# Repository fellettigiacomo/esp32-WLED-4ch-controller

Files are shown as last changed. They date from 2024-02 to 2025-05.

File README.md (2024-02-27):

# esp32-WLED-4ch-controller
Hardware design for a 4 channel WLED controller with built in relays for power saving and level shifter for better signal integrity with long data cables.<br>
<br>

## Manufacturing
I tried to make this board as cheap as possibile using JLCPCB basics part for PCBA, however, since there are many extended parts the final cost should be around 25$/board + shipping
<br>All parts should be compatible with the JLCPCB assembly, otherwise, feel free to send me a pull request.
<br>Looking for a cheaper alternative? i've uploaded a version of the board without the esp32 related hardware, with the headers to plug a whole dev-kit, saving out on extended parts.

## Compatibility and capabilites
This PCB supports up to 4 addressable led strips:
Only strips that works with 5V are compatible. 
Compatible strips: WS2811 - WS2812B - TM1829 (and other with 5V, DATA, GND). Check [the wled wiki](https://kno.wled.ge/basics/compatible-led-strips/) for more info
<br>The board allows for a maximum current of around 100W (20A) max. Maximum current for a single relay is 10A (50W)

## Flashing
To flash the firmware, follow these steps:
- connect via USB-C or with serial UART (use test points TX, RX, 3.3V, GND)
- use the WLED web installer powered by Esp Web Tools at https://install.wled.me/
- connect to serial port and flash
- after installing, connect to the address provided from the web installer, or connect to the WLED AP
- done! enjoy your addressable IoT leds :D

## Licence
CERN Open Hardware License - S (CERN-OHL-S)

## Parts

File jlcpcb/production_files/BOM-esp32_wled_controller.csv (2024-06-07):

Comment | Designator | Footprint | LCSC
EL817 | U4,U5,U6,U7 | OPTO-SMD-4_L4.6-W6.5-P2.54-LS10.3-TL | C106900
1K | R3,R6,R7 | R_0402_1005Metric_Pad0.72x0.64mm_HandSolder | C11702
100nF | C1,C11,C12,C2,C4,C5 | C_0402_1005Metric_Pad0.74x0.62mm_HandSolder | C1525
1K | R13,R14,R15,R16,R17,R18,R19,R8 | R_0805_2012Metric_Pad1.20x1.40mm_HandSolder | C17513
4u7 | C6 | C_0805_2012Metric_Pad1.18x1.45mm_HandSolder | C1779
100R | R20,R21,R22,R23 | R_0402_1005Metric_Pad0.72x0.64mm_HandSolder | C25076
22R | R10,R11 | R_0402_1005Metric_Pad0.72x0.64mm_HandSolder | C25092
10K | R1,R2,R9 | R_0402_1005Metric_Pad0.72x0.64mm_HandSolder | C25744
5K1 | R4,R5 | R_0402_1005Metric_Pad0.72x0.64mm_HandSolder | C25905
USB_C_Receptacle_USB2.0_16P | J1 | USB_C_Receptacle_G-Switch_GT-USB-7010ASV | C2988369
SW_SPST | SW1,SW2 | SW_Push_1P1T_XKB_TS-1187A | C318884
SRD-05VDC-SL-C | K1,K2,K3,K4 | RELAY_SRD-05VDC-SL-C | C35449
SN74AHCT125PWR | U9 | SOP65P640X120-14N | C36365
SS8050 | Q1,Q2,Q3,Q4,Q5,Q6 | SOT-23 | C431710
22u | C10,C13,C3,C7,C9 | C_0805_2012Metric_Pad1.18x1.45mm_HandSolder | C45783
Screw_Terminal_01x03 | J2,J3,J4,J5 | CONN-TH_3P-P5.00_KF301-5.0-3P | C474882
Screw_Terminal_01x02 | J6,J7 | CONN-TH_P5.00_KF301-5.0-2P | C474885
CP2104 | U3 | QFN-24-1EP_4x4mm_P0.5mm_EP2.6x2.6mm | C47742
AMS1117-3.3 | U2 | SOT-223-3_TabPin2 | C6186
C7420350 | D1,D2,D3,D9 | D_MELF_Handsoldering | C7420350
ESP32-S2-WROOM-1-N4(4MB) | U8 | WIFI-SMD_ESP32-S2-WROVER-I | C7463335
RED_LED | RELAY1,RELAY2,RELAY3,RELAY4 | LED_0805_2012Metric_Pad1.15x1.40mm_HandSolder | C84256

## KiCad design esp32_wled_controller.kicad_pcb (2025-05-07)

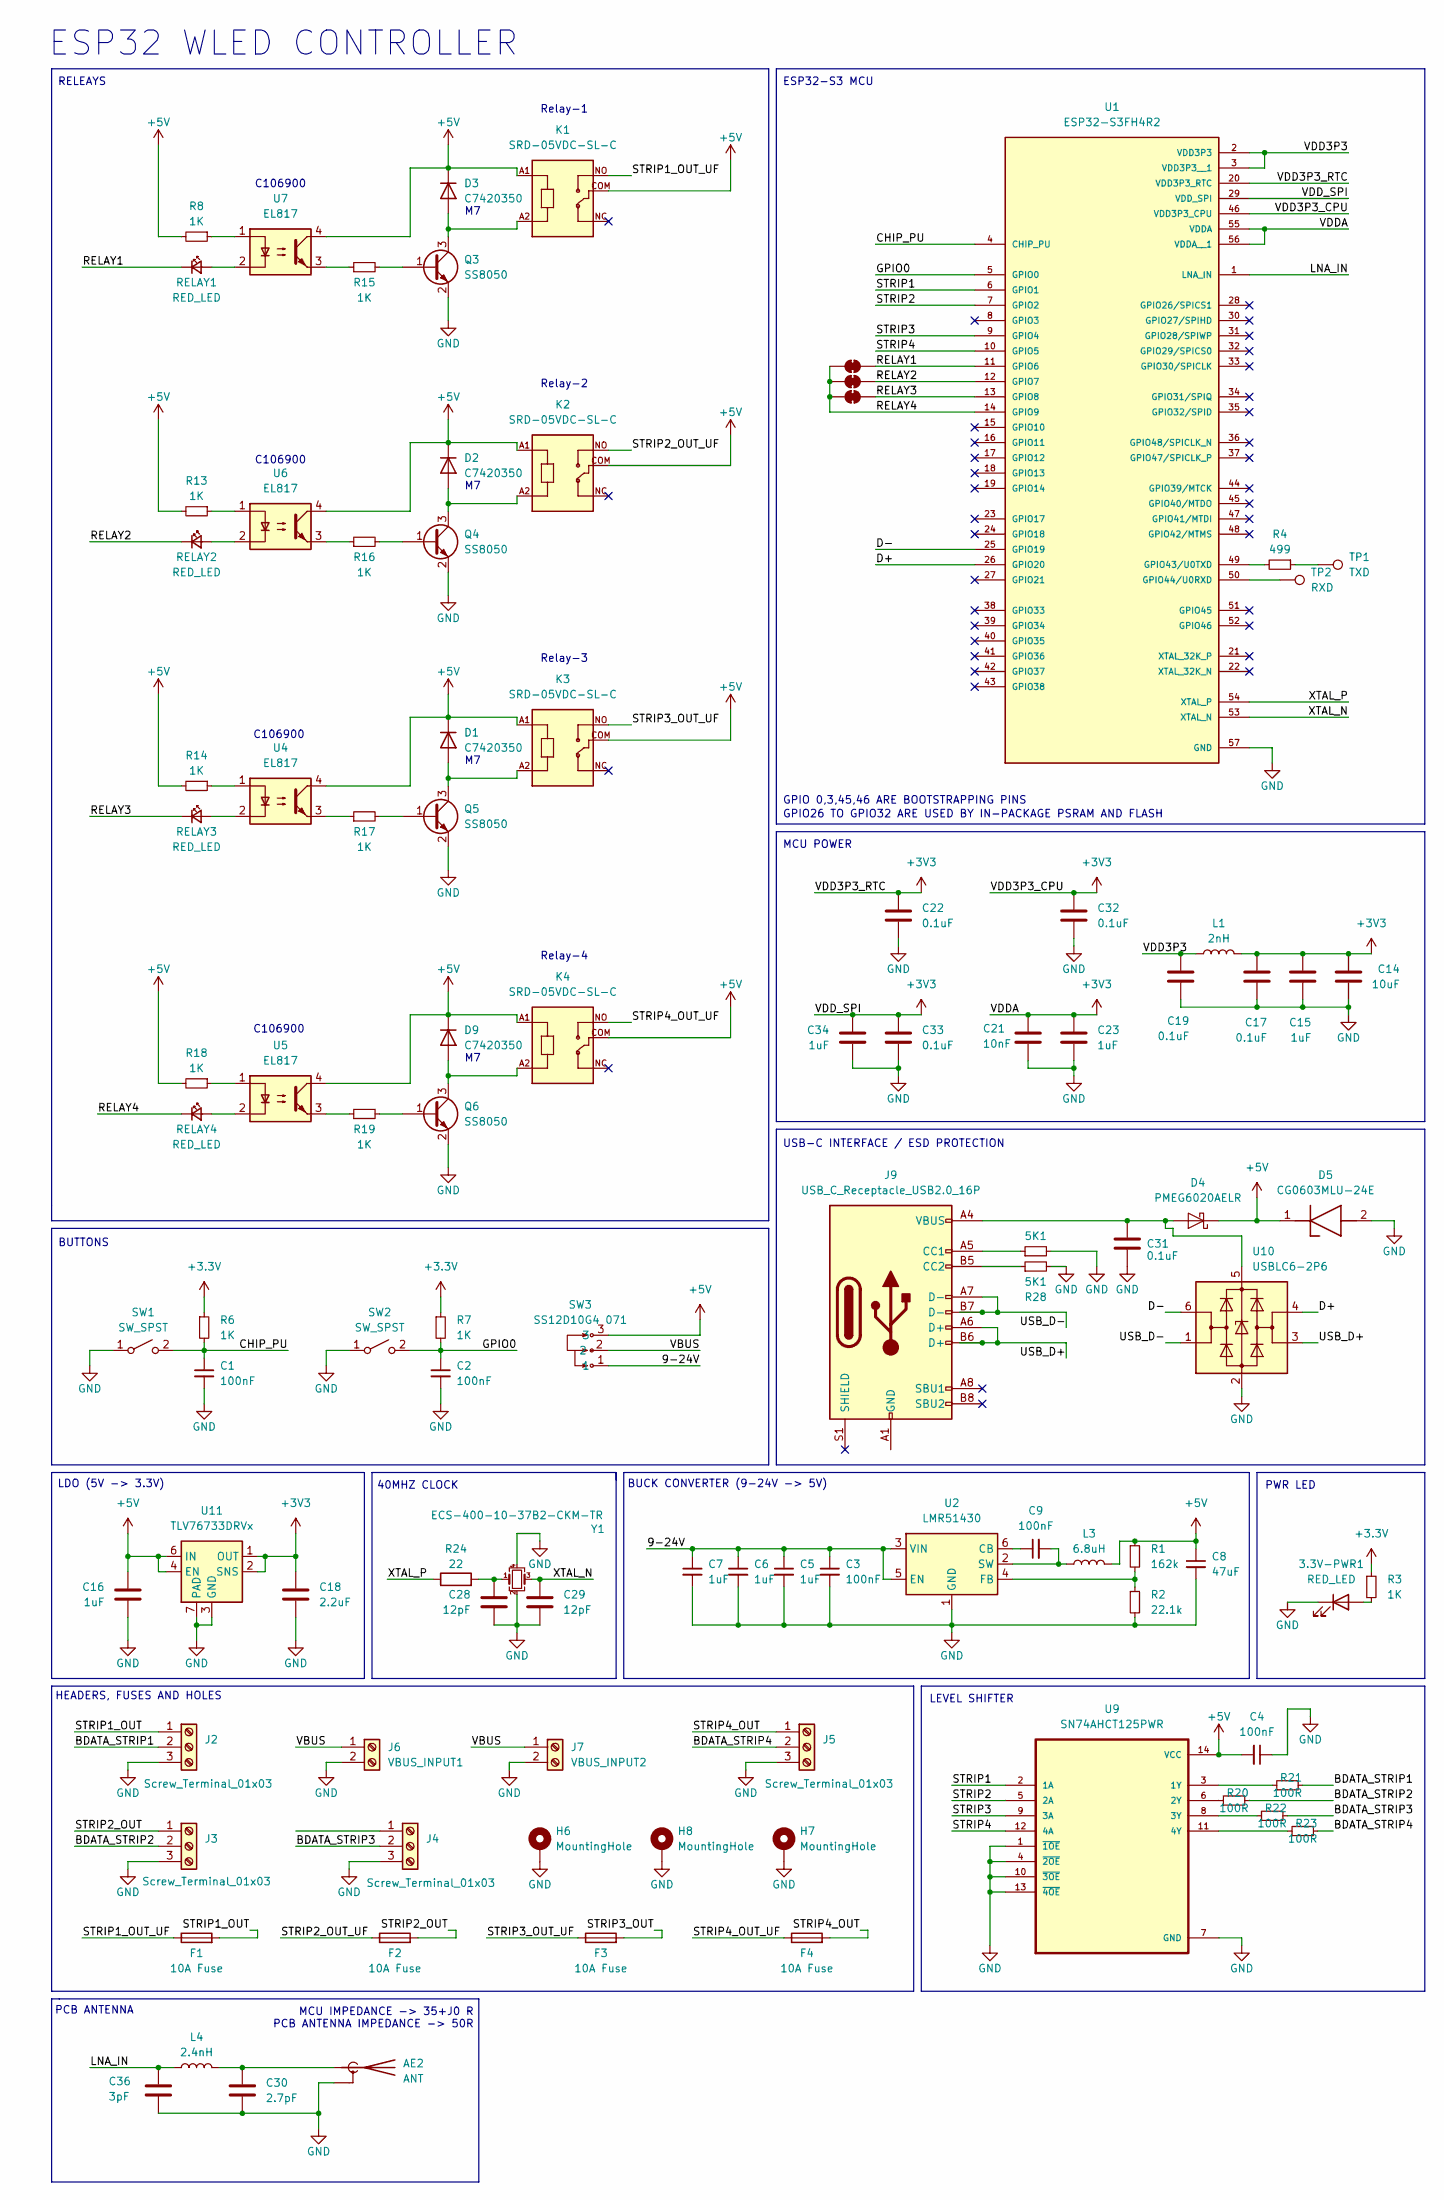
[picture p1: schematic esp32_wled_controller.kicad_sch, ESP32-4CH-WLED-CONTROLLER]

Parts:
3.3V-PWR1: RED_LED; LED_0805_2012Metric_Pad1.15x1.40mm_HandSolder
AE2: ANT; Texas_SWRA117D_2.4GHz_Left
C1, C2, C4: 100nF; C_0402_1005Metric_Pad0.74x0.62mm_HandSolder; LCSC C1525
C3, C9: 100nF; C_0402_1005Metric_Pad0.74x0.62mm_HandSolder
C5, C6, C7, C15, C23, C34: 1uF; C_0402_1005Metric_Pad0.74x0.62mm_HandSolder
C8: 47uF; C_0402_1005Metric_Pad0.74x0.62mm_HandSolder
C14: 10uF; C_0201_0603Metric_Pad0.64x0.40mm_HandSolder
C16: 1uF; C_0201_0603Metric_Pad0.64x0.40mm_HandSolder
C17, C19, C22, C31, C32, C33: 0.1uF; C_0402_1005Metric_Pad0.74x0.62mm_HandSolder
C18: 2.2uF; C_0402_1005Metric_Pad0.74x0.62mm_HandSolder
C21: 10nF; C_0201_0603Metric_Pad0.64x0.40mm_HandSolder
C28, C29: 12pF; C_0201_0603Metric_Pad0.64x0.40mm_HandSolder
C30: 2.7pF; C_0201_0603Metric_Pad0.64x0.40mm_HandSolder
C36: 3pF; C_0201_0603Metric_Pad0.64x0.40mm_HandSolder
D1, D2, D3, D9: C7420350; D_MELF_Handsoldering; LCSC C7420350
D4: PMEG6020AELR; Nexperia_CFP3_SOD-123W
D5: CG0603MLU-24E; R0603; Manufacturer_Part_Number CG0603MLU-24E; Mouser Part Number 652-CG0603MLU-24E
F1, F2, F3, F4: 10A Fuse; Fuseholder_Blade_Mini_Keystone_3568
H6, H7, H8: MountingHole; MountingHole_2.5mm_Pad
J2, J3, J4, J5: Screw_Terminal_01x03; CONN-TH_3P-P5.00_KF301-5.0-3P
J6: VBUS_INPUT1; CONN-TH_P5.00_KF301-5.0-2P
J7: VBUS_INPUT2; CONN-TH_P5.00_KF301-5.0-2P
J9: USB_C_Receptacle_USB2.0_16P; USB_C_Receptacle_G-Switch_GT-USB-7010ASV; LCSC C2988369
JP1, JP2, JP3: SolderJumper_2_Bridged; SolderJumper-2_P1.3mm_Open_TrianglePad1.0x1.5mm
K1, K2, K3, K4: SRD-05VDC-SL-C; RELAY_SRD-05VDC-SL-C; LCSC C35449
L1: 2nH; L_0402_1005Metric
L3: 6.8uH; IND-SMD_L4.4-W4.2
L4: 2.4nH; L_0201_0603Metric
Q3, Q4, Q5, Q6: SS8050; SOT-23; LCSC C431710
R1: 162k; R_0805_2012Metric_Pad1.20x1.40mm_HandSolder
R2: 22.1k; R_0805_2012Metric_Pad1.20x1.40mm_HandSolder
R3, R6, R7: 1K; R_0402_1005Metric_Pad0.72x0.64mm_HandSolder; LCSC C17513
R4: 499; R_0402_1005Metric_Pad0.72x0.64mm_HandSolder
R8, R13, R14, R15, R16, R17, R18, R19: 1K; R_0805_2012Metric_Pad1.20x1.40mm_HandSolder; LCSC C17513
R20, R21, R22, R23: 100R; R_0402_1005Metric_Pad0.72x0.64mm_HandSolder; LCSC C25076
R24: 22; R_0402_1005Metric
R25, R28: 5K1; R_0402_1005Metric_Pad0.72x0.64mm_HandSolder; LCSC C25905
RELAY1, RELAY2, RELAY3, RELAY4: RED_LED; LED_0805_2012Metric_Pad1.15x1.40mm_HandSolder; LCSC C84256
SW1, SW2: SW_SPST; SW_Push_1P1T_XKB_TS-1187A
SW3: SS12D10G4 071; SW-TH_SHOU-HAN_SS12D10G4; LCSC Part C2887259
TP1: TXD
TP2: RXD
U1: ESP32-S3FH4R2; QFN40P700X700X90-57N; PARTREV 1.8mm
U2: LMR51430; SOT-23-6
U4, U5, U6, U7: EL817; OPTO-SMD-4_L4.6-W6.5-P2.54-LS10.3-TL; LCSC C106900
U9: SN74AHCT125PWR; SOP65P640X120-14N; LCSC C36365
U10: USBLC6-2P6; SOT-666
U11: TLV76733DRVx; WSON-6-1EP_2x2mm_P0.65mm_EP1x1.6mm_ThermalVias
Y1: ECS-400-10-37B2-CKM-TR; Crystal_SMD_2016-4Pin_2.0x1.6mm

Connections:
+3.3V: R3.1, R6.1, R7.1
+3V3: C14.1, C15.1, C17.1, C18.1, C21.1, C22.1, C23.1, C32.1, C33.1, C34.1, L1.1, U1.20 (VDD3P3_RTC), U1.29 (VDD_SPI), U1.46 (VDD3P3_CPU), U1.55 (VDDA), U1.56 (VDDA__1), U11.1 (OUT), U11.2 (SNS)
+5V: C4.2, C8.1, C16.1, D1.1 (K), D2.1 (K), D3.1 (K), D4.1 (K), D5.1 (K), D9.1 (K), K1.A1, K1.COM, K2.A1, K2.COM, K3.A1, K3.COM, K4.A1, K4.COM, L3.2, R1.1, R8.2, R13.2, R14.2, R18.2, SW3.3, U4.4, U5.4, U6.4, U7.4, U9.14 (VCC), U11.4 (EN), U11.6 (IN)
/9-24V: C3.1, C5.1, C6.1, C7.1, SW3.1, U2.3 (VIN), U2.5 (EN)
/BDATA_STRIP1: J2.2, R21.2
/BDATA_STRIP2: J3.2, R20.2
/BDATA_STRIP3: J4.2, R22.2
/BDATA_STRIP4: J5.2, R23.2
/CHIP_PU: C1.1, R6.2, SW1.2 (B), U1.4 (CHIP_PU)
/D+: U1.26 (GPIO20), U10.4 (I/O2)
/D-: U1.25 (GPIO19), U10.6 (I/O1)
/GPIO0: C2.1, R7.2, SW2.2 (B), U1.5 (GPIO0)
/LNA_IN: C36.1, L4.2, U1.1 (LNA_IN)
/RELAY1: JP3.2 (B), RELAY1.1 (K), U1.11 (GPIO6)
/RELAY2: JP2.2 (B), RELAY2.1 (K), U1.12 (GPIO7)
/RELAY3: JP1.2 (B), RELAY3.1 (K), U1.13 (GPIO8)
/RELAY4: JP1.1 (A), JP2.1 (A), JP3.1 (A), RELAY4.1 (K), U1.14 (GPIO9)
/STRIP1: U1.6 (GPIO1), U9.2 (1A)
/STRIP1_OUT: F1.2, J2.1
/STRIP1_OUT_UF: F1.1, K1.NO
/STRIP2: U1.7 (GPIO2), U9.5 (2A)
/STRIP2_OUT: F2.2, J3.1
/STRIP2_OUT_UF: F2.1, K2.NO
/STRIP3: U1.9 (GPIO4), U9.9 (3A)
/STRIP3_OUT: F3.2
/STRIP3_OUT_UF: F3.1, K3.NO
/STRIP4: U1.10 (GPIO5), U9.12 (4A)
/STRIP4_OUT: F4.2, J5.1
/STRIP4_OUT_UF: F4.1, K4.NO
/USB_D+: J9.A6 (D+), J9.B6 (D+), U10.3 (I/O2); also elsewhere on the board
/USB_D-: J9.A7 (D-), J9.B7 (D-), U10.1 (I/O1); also elsewhere on the board
/VBUS: J6.1, J7.1, SW3.2
/VDD3P3: C19.1, L1.2, U1.2 (VDD3P3), U1.3 (VDD3P3__1)
/XTAL_N: C29.1, U1.53 (XTAL_N), Y1.3
/XTAL_P: R24.1, U1.54 (XTAL_P)
GND: 3.3V-PWR1.1 (K), AE2.2 (Shield), C1.2, C2.2, C3.2, C4.1, C5.2, C6.2, C7.2, C8.2, C14.2, C15.2, C16.2, C17.2, C18.2, C19.2, C21.2, C22.2, C23.2, C28.2, C29.2, C30.2, C31.2, C32.2, C33.2, C34.2, C36.2, D5.2 (A), H6.1, H7.1, H8.1, J2.3, J3.3, J4.3, J5.3, J6.2, J7.2, Q3.2 (E), Q4.2 (E), Q5.2 (E), Q6.2 (E), R2.2, R25.2, R28.2, SW1.1 (A), SW2.1 (A), U1.57 (GND), U2.1 (GND), U9.1 (~1OE), U9.4 (~2OE), U9.7 (GND), U9.10 (~3OE), U9.13 (~4OE), U10.2 (GND), U11.3 (GND), U11.5 (GND), U11.7 (PAD), Y1.2, Y1.4; also elsewhere on the board
unnamed 36: 3.3V-PWR1.2 (A), R3.2; also elsewhere on the board
unnamed: AE2.1 (A), C30.1, L4.1
unnamed: C28.1, R24.2, Y1.1
unnamed: D1.2 (A), K3.A2, Q5.3 (C)
unnamed: D2.2 (A), K2.A2, Q4.3 (C)
unnamed: D3.2 (A), K1.A2, Q3.3 (C)
unnamed 42: C31.1, D4.2 (A), J9.A4 (VBUS), J9.A9 (VBUS), J9.B4 (VBUS), J9.B9 (VBUS), U10.5 (VBUS); also elsewhere on the board
unnamed: D9.2 (A), K4.A2, Q6.3 (C)
unnamed 44: J9.A5 (CC1), R25.1; also elsewhere on the board
unnamed 45: J9.B5 (CC2), R28.1; also elsewhere on the board
unnamed: J9.A1 (GND), J9.A12 (GND), J9.B1 (GND), J9.B12 (GND)
unnamed: Q3.1 (B), R15.2
unnamed: Q4.1 (B), R16.2
unnamed: Q5.1 (B), R17.2
unnamed: Q6.1 (B), R19.2
unnamed: R4.1, TP1.1
unnamed: R8.1, U7.1
unnamed: R13.1, U6.1
unnamed: R14.1, U4.1
unnamed: R15.1, U7.3
unnamed: R16.1, U6.3
unnamed: R17.1, U4.3
unnamed: R18.1, U5.1
unnamed: R19.1, U5.3
unnamed: RELAY1.2 (A), U7.2
unnamed: RELAY2.2 (A), U6.2
unnamed: RELAY3.2 (A), U4.2
unnamed: RELAY4.2 (A), U5.2
unnamed: R4.2, U1.49 (GPIO43/U0TXD)
unnamed: TP2.1, U1.50 (GPIO44/U0RXD)
unnamed: C9.1, U2.6 (CB)
unnamed: R1.2, R2.1, U2.4 (FB)
unnamed: C9.2, L3.1, U2.2 (SW)
unnamed: R21.1, U9.3 (1Y)
unnamed: R20.1, U9.6 (2Y)
unnamed: R22.1, U9.8 (3Y)
unnamed: R23.1, U9.11 (4Y)

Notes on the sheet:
Relay-2
MCU IMPEDANCE -> 35+J0 R PCB ANTENNA IMPEDANCE -> 50R
Relay-4
GPIO26 TO GPIO32 ARE USED BY IN-PACKAGE PSRAM AND FLASH
LEVEL SHIFTER
MCU POWER
C106900
ESP32-S3 MCU
GPIO 0,3,45,46 ARE BOOTSTRAPPING PINS
HEADERS, FUSES AND HOLES
ESP32 WLED CONTROLLER
USB-C INTERFACE / ESD PROTECTION
BUCK CONVERTER (9-24V -> 5V)
BUTTONS
RELEAYS
PCB ANTENNA
Relay-3
40MHZ CLOCK
LDO (5V -> 3.3V)
Relay-1
PWR LED

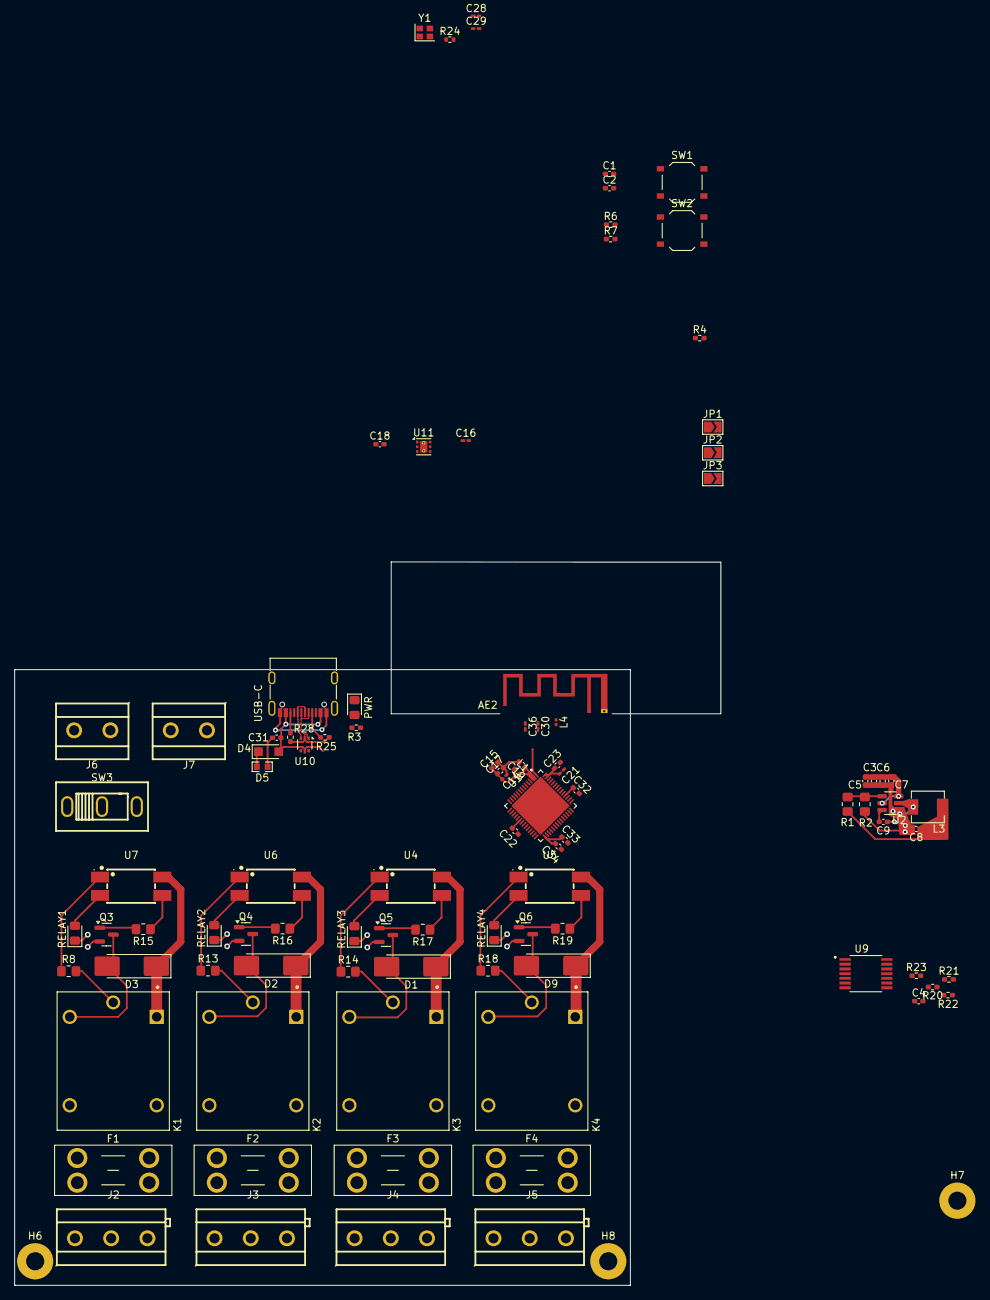
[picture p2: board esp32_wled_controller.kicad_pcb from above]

Board: 4 copper layers, 97.5 x 99.9 mm, 100 parts (0 on the bottom side), 70 nets.

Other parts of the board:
PWR: RED_LED; LED_0805_2012Metric_Pad1.15x1.40mm_HandSolder
USB-C: USB_C_Receptacle_USB2.0_16P; USB_C_Receptacle_G-Switch_GT-USB-7010ASV

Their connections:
/USB_D+: USB-C.A6 (D+), USB-C.B6 (D+); also elsewhere on the board
/USB_D-: USB-C.A7 (D-), USB-C.B7 (D-); also elsewhere on the board
GND: PWR.1 (K); also elsewhere on the board
unnamed 36: PWR.2 (A); also elsewhere on the board
unnamed 42: USB-C.A4 (VBUS), USB-C.A9 (VBUS), USB-C.B4 (VBUS), USB-C.B9 (VBUS); also elsewhere on the board
unnamed 44: USB-C.A5 (CC1); also elsewhere on the board
unnamed 45: USB-C.B5 (CC2); also elsewhere on the board
unnamed: USB-C.A1 (GND), USB-C.A12 (GND), USB-C.B1 (GND), USB-C.B12 (GND)

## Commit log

2024-02-27 board version 1.0
    [bom.csv, designators.csv, esp32_wled_controller.kicad_pcb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]
2024-02-27 added board render
2024-05-08 deleted old production files
    [bom.csv, designators.csv, positions.csv]
2024-05-08 board revision 1.1
    [esp32_wled_controller.kicad_pcb, esp32_wled_controller.kicad_sch]
2024-05-08 added production files
    [bom.csv, designators.csv, positions.csv]
2024-05-08 deleted esp32_wled_controller.kicad_prl
2024-05-08 added header version revision 1.1
    [bom.csv, designators.csv, esp32_wled_controller.kicad_pcb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]
2024-05-28 updated board render to v1.1
    [bom.csv, designators.csv, esp32_wled_controller.kicad_pcb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]
2024-05-28 board rev 1.2, cleanup
    [BOM-esp32_wled_controller.csv, bom.csv, designators.csv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]
2024-05-28 board render for rev 1.2
2024-05-30 changed terminal block footprint
    [BOM-esp32_wled_controller.csv, esp32_wled_controller.kicad_pcb, esp32_wled_controller.kicad_sch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]
2024-06-01 final 1.2 release
    [BOM-esp32_wled_controller.csv, esp32_wled_controller.kicad_pcb, esp32_wled_controller.kicad_sch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]
2024-06-05 fix optocoupler footprint, fix layout
    [BOM-esp32_wled_controller.csv, esp32_wled_controller.kicad_pcb, esp32_wled_controller.kicad_sch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]
2024-06-07 fix R3, R6, R7 footprint
    [BOM-esp32_wled_controller.csv]
2024-06-11 add 3d models, new board render
    [esp32_wled_controller.kicad_pcb]
2025-05-02 add rev 1.3 schematic: esp32 chip, pcb chip antenna, boost converter
    [esp32_wled_controller.kicad_sch]
2025-05-04 add pcb antenna
    [esp32_wled_controller.kicad_sch]
2025-05-07 inital rev 1.3 pcb design
    [esp32_wled_controller.kicad_pcb, esp32_wled_controller.kicad_sch]
